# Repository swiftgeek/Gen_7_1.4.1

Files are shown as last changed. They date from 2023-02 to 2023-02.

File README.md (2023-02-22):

Known issues:

* PA6 missing trace to MCU and a short between PA6/PA7. Upstream `.pcb` file
doesn't match gerbers and PDFs/PNGs
* Board outline doesn't work well with OBV

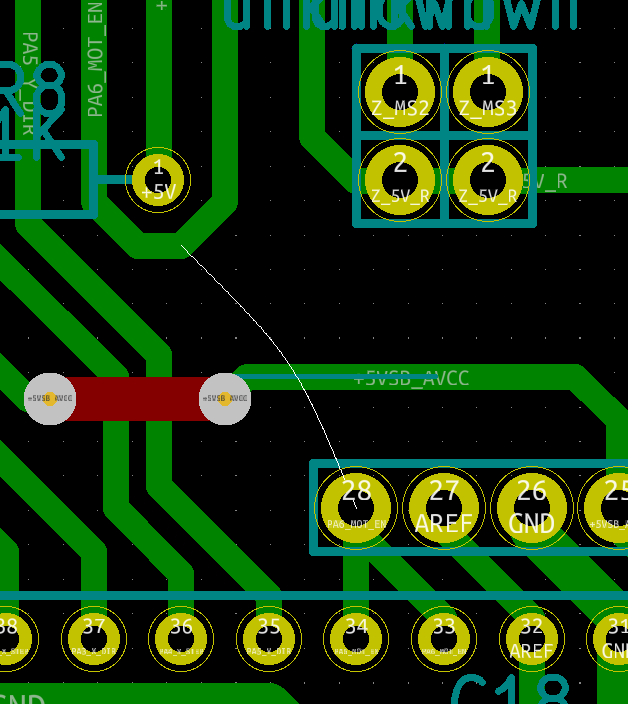
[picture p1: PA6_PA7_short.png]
Picture of short and missing trace Short and missng trace


TODO:

* Try importing gerber traces/layout into `pcb`/`pcbnew`, otherwise
set gerber render and background and try laying traces over it exactly.
* Generate PDFs and gerbers once fixed

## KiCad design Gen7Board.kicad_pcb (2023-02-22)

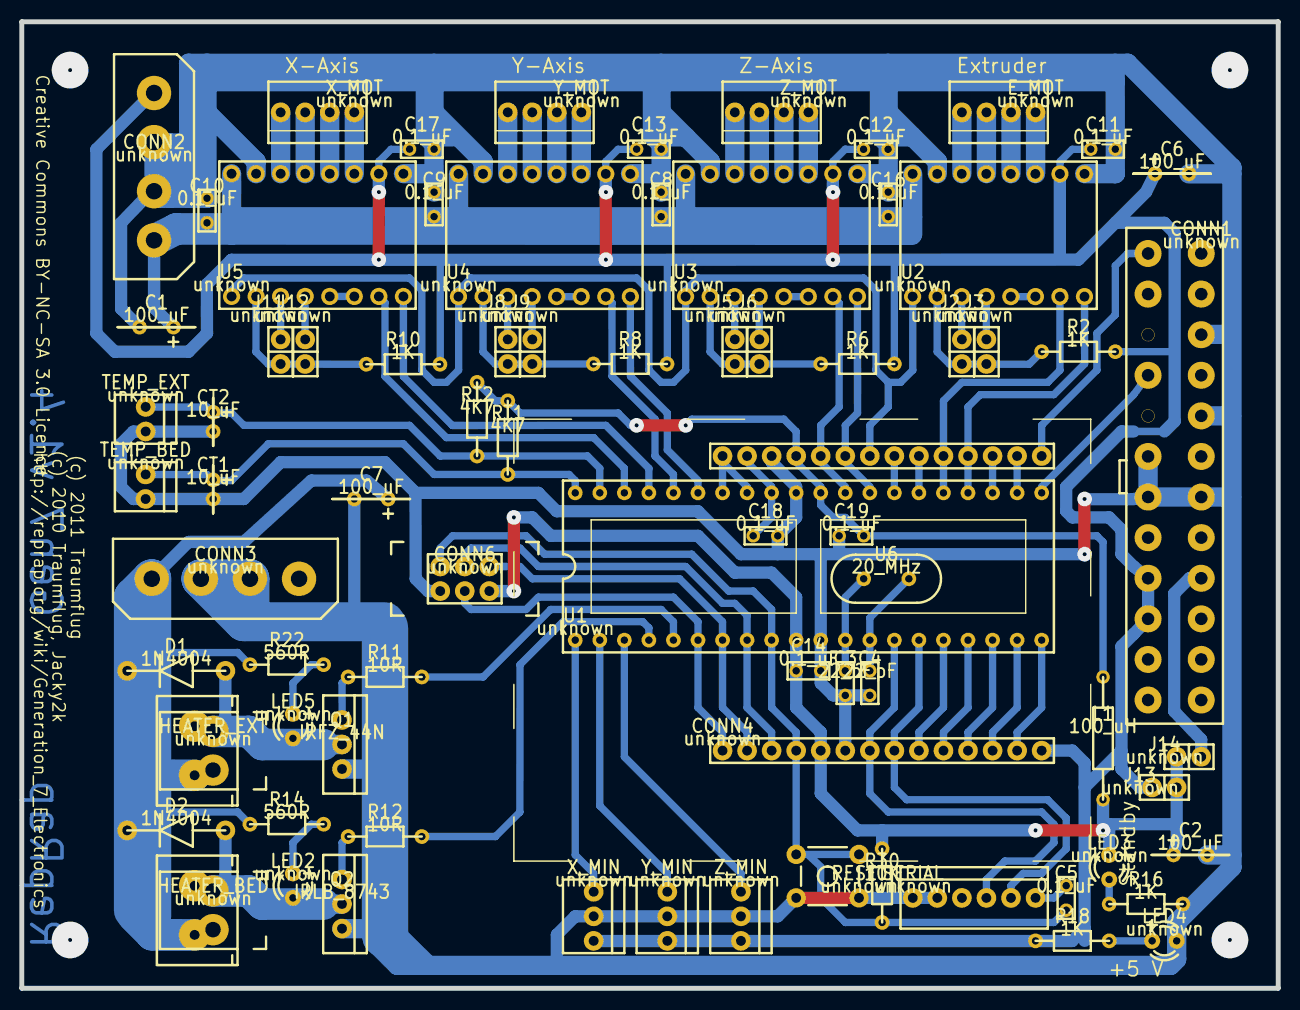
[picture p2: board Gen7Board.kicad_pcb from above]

Board: 2 copper layers, 130.0 x 100.0 mm, 76 parts (0 on the bottom side), 84 nets.

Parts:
C1: 100_uF; RCY3mm5_dup15
C2: 100_uF; RCY3mm5_dup26
C3: 22_pF; ACY100_dup1
C4: 22_pF; ACY100_dup13
C5: 0.1_uF; ACY100_dup7
C6: 100_uF; RCY3mm5
C7: 100_uF; RCY3mm5_dup42
C8: 0.1_uF; ACY100_dup36
C9: 0.1_uF; ACY100_dup37
C10: 0.1_uF; ACY100_dup38
C11: 0.1_uF; ACY100_dup39
C12: 0.1_uF; ACY100
C13: 0.1_uF; ACY100_dup0
C14: 0.1_uF; ACY100_dup2
C16: 0.1_uF; ACY100_dup14
C17: 0.1_uF; ACY100_dup33
C18: 0.1_uF; ACY100_dup34
C19: 0.1_uF; ACY100_dup35
CONN1: unknown; ATX20+4-1
CONN2: unknown; MOLEX_4_PIN
CONN3: unknown; MOLEX_4_PIN_dup40
CONN4: unknown; ExtensionBoard
CONN6: unknown; ICSP_HEADER
CT1: 10_uF; RCY2mm_dup50
CT2: 10_uF; RCY2mm
D1: 1N4004; 1N4004_dup48
D2: 1N4004
E_MOT: unknown; 100-4-1_dup51
HEATER_BED: unknown; Combi-2-1_dup44
HEATER_EXT: unknown; Combi-2-1
J2: unknown; JUMPER2_1_dup22
J3: unknown; JUMPER2_1_dup23
J5: unknown; JUMPER2_1_dup24
J6: unknown; JUMPER2_1_dup25
J8: unknown; JUMPER2_1_dup3
J9: unknown; JUMPER2_1_dup6
J11: unknown; JUMPER2_1_dup4
J12: unknown; JUMPER2_1_dup5
J13: unknown; JUMPER2_1
J14: unknown; JUMPER2_1_dup9
L1: 100_uH; ACY500_1
LED2: unknown; LED3_1_dup45
LED3: unknown; LED3_1_dup8
LED4: unknown; LED3_1_dup12
LED5: unknown; LED3_1
Q1: IRFZ_44N; TO-220-1
Q2: IRLB_8743; TO-220-1_dup41
R2: 1K; ACY300_1_dup27
R6: 1K; ACY300_1_dup28
R8: 1K; ACY300_1_dup29
R10: 1K; ACY300_1_dup30
R11: 10R; ACY300_1_dup46
R12: 10R; ACY300_1_dup43
R14: 560R; ACY300_1_dup47
R16: 1K; ACY300_1_dup11
R18: 1K; ACY300_1_dup31
R22: 560R; ACY300_1
R30: 10K; ACY300_1_dup20
RESET: unknown; MJTP1230-1
RT1: 4K7; ACY300_1_dup32
RT2: 4K7; ACY300_1_dup10
SERIAL: unknown; 100-6-1
TEMP_BED: unknown; 100-2-1
TEMP_EXT: unknown; 100-2-1_dup49
U1: unknown; DIP40_1
U2: unknown; POLOLUSTEPPER-1_dup17
U3: unknown; POLOLUSTEPPER-1_dup19
U4: unknown; POLOLUSTEPPER-1
U5: unknown; POLOLUSTEPPER-1_dup18
U6: 20_MHz; CRYSTAL_AS
X_MIN: unknown; 100-3-1
X_MOT: unknown; 100-4-1
Y_MIN: unknown; 100-3-1_dup16
Y_MOT: unknown; 100-4-1_dup52
Z_MIN: unknown; 100-3-1_dup21
Z_MOT: unknown; 100-4-1_dup53

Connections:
+3.3V_ATX: CONN1.11, CONN4.15
+5V: C6.1, C11.2, C12.2, C13.2, C17.2, CONN1.19, CONN1.20, CONN2.4, CONN4.14, J13.1, R2.1, R6.1, R8.1, R10.1, R18.1, U2.10, U3.10, U4.10, U5.10, X_MIN.3, Y_MIN.3, Z_MIN.3
+5VSB: C2.1, C14.2, CONN4.5, CONN6.2, J13.2, J14.1, L1.1, LED3.1, R30.2, U1.10
+5VSB_ATX: CONN1.9, J14.2
+5VSB_AVCC: C19.1, CONN4.25, L1.2, RT1.2, RT2.2, U1.30
AREF: C18.1, CONN4.27, U1.32
E_1A: E_MOT.2, U2.12
E_1B: E_MOT.1, U2.11
E_2A: E_MOT.3, U2.13
E_2B: E_MOT.4, U2.14
E_5V_R: J2.2, J3.2, R2.2, U2.2
E_MS2: J2.1, U2.3
E_MS3: J3.1, U2.4
E_SLP_RST: U2.5, U2.6
GND: C1.2, C2.2, C3.2, C4.2, C6.2, C7.2, C8.2, C9.2, C10.2, C11.1, C12.1, C13.1, C14.1, C16.2, C17.1, C18.2, C19.2, CONN1.3, CONN1.5, CONN1.7, CONN1.16, CONN1.17, CONN2.2, CONN2.3, CONN3.2, CONN3.3, CONN4.6, CONN4.26, CONN6.6, CT1.2, CT2.2, LED4.2, Q1.3, Q2.3, R16.2, RESET.1, SERIAL.1, SERIAL.2, TEMP_BED.2, TEMP_EXT.2, U1.11, U1.31, U2.9, U2.15, U3.9, U3.15, U4.9, U4.15, U5.9, U5.15, X_MIN.2, Y_MIN.2, Z_MIN.2
GND_HEATER_BED: D2.2, HEATER_BED.2, LED2.2, Q2.2
GND_HEATER_EXT: D1.2, HEATER_EXT.2, LED5.2, Q1.2
LED2_R: LED2.1, R14.2
LED3_R: LED3.2, R16.1
LED4_R: LED4.1, R18.2
LED5_R: LED5.1, R22.2
PA0_TEMP_BED: CT1.1, RT1.1, TEMP_BED.1, U1.40
PA1_TEMP_EXT: CT2.1, RT2.1, TEMP_EXT.1, U1.39
PA2_X_STEP: U1.38, U5.7
PA3_X_DIR: U1.37, U5.8
PA4_Y_STEP: U1.36, U4.7
PA5_Y_DIR: U1.35, U4.8
PA6_MOT_EN: CONN4.22, CONN4.28, U1.33, U1.34, U2.1, U3.1, U4.1, U5.1
PB0_X_MIN: U1.1, X_MIN.1
PB1_Y_MIN: U1.2, Y_MIN.1
PB2_Z_MIN: U1.3, Z_MIN.1
PB3_HEATER_BED: R12.2, U1.4
PB3_HEATER_BED_R: Q2.1, R12.1
PB3_HEATER_EXT_R: Q1.1, R11.1
PB4_HEATER_EXT: R11.2, U1.5
PB5_ICSP_MOSI: CONN4.1, CONN6.4, U1.6
PB6_ICSP_MISO: CONN4.2, CONN6.1, U1.7
PB7_ICSP_SCK: CONN4.3, CONN6.3, U1.8
PC0_SCL: CONN4.16, U1.22
PC1_SDA: CONN4.17, U1.23
PC2_E_STEP: CONN4.18, U1.24, U2.8
PC3_E_DIR: CONN4.19, U1.25, U2.7
PC4_TDO: CONN4.20, U1.26
PC5_TDI: CONN4.21, U1.27
PC6_Z_DIR: CONN4.23, U1.28, U3.8
PC7_Z_STEP: CONN4.24, U1.29, U3.7
PD0_RXD0: CONN4.7, SERIAL.4, U1.14
PD1_TXD0: CONN4.8, SERIAL.5, U1.15
PD2_RXD1_INT0: CONN4.9, U1.16
PD3_TXD1_INT1: CONN4.10, U1.17
PD4_XCK1_OC1B: CONN4.11, U1.18
PD5_OC1A: CONN4.12, U1.19
PD6_OC2B_ICP: CONN4.13, U1.20
PD7_ATX_PS_ON: CONN1.14, U1.21
RESET: C5.1, CONN4.4, CONN6.5, R30.1, RESET.2, U1.9
RESET_C: C5.2, SERIAL.6
Vheat: C7.1, CONN3.1, D1.1, D2.1, HEATER_BED.1, HEATER_EXT.1, R14.1, R22.1
Vmot: C1.1, C8.1, C9.1, C10.1, C16.1, CONN2.1, U2.16, U3.16, U4.16, U5.16
XTAL1: C4.1, U1.13, U6.1
XTAL2: C3.1, U1.12, U6.2
X_1A: U5.12, X_MOT.2
X_1B: U5.11, X_MOT.1
X_2A: U5.13, X_MOT.3
X_2B: U5.14, X_MOT.4
X_5V_R: J11.2, J12.2, R10.2, U5.2
X_MS2: J11.1, U5.3
X_MS3: J12.1, U5.4
X_SLP_RST: U5.5, U5.6
Y_1A: U4.12, Y_MOT.2
Y_1B: U4.11, Y_MOT.1
Y_2A: U4.13, Y_MOT.3
Y_2B: U4.14, Y_MOT.4
Y_5V_R: J8.2, J9.2, R8.2, U4.2
Y_MS2: J8.1, U4.3
Y_MS3: J9.1, U4.4
Y_SLP_RST: U4.5, U4.6
Z_1A: U3.12, Z_MOT.2
Z_1B: U3.11, Z_MOT.1
Z_2A: U3.13, Z_MOT.3
Z_2B: U3.14, Z_MOT.4
Z_5V_R: J5.2, J6.2, R6.2, U3.2
Z_MS2: J5.1, U3.3
Z_MS3: J6.1, U3.4
Z_SLP_RST: U3.5, U3.6

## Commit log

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2010-10-17 Gen7Board.pcb: fix the layer grouping to actually have a working solder and component side.
2010-10-17 Fixed a few things around the ATX20 connector:
    - The ATX20 symbol had "J?" as the default name which clashes with jumpers.
    - The ATX20 footprint had in addition to the above wrong pin numbers.
    - Fitted the new ATX20 connector footprint onto the board.
    - Removed the GND pad as this somehow doesn't work and there's more
    than enough space on the wide GND tracks.
    [Gen7Board.sch]
2010-10-17 Fix the Molex KK 100 3-pin connector footprint to comply with the data sheet.
2010-10-17 Gen7Board: replace 2-pin jumpers with solder jumpers.
    [Gen7Board.sch]
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2010-10-30 Gen7Board: modify the schematic to match the recent turn of the endstop connectors in the PCB.
    [Gen7Board.sch]
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2010-10-30 Made a new ICSP header symbol (for the pin labels) and fitted it into the schematics.
    [Gen7Board.sch]
2010-10-30 Following a contribution by Lanthan: Made a footprint for the ICSP header with matching pin numbering and wired the thing into the pcb.
    [Gen7Board.sch]
2010-12-09 Changed Opto Endstop connectors to match the layout of RAMPS.
    Yes, this is yet again and no, the endstops them selfs are not done yet.
    [Gen7Board.sch]
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2010-12-15 Board, by Jacky2k: Allow traces between between reset switch pins.
    Also add a data sheet for that switch and rename the footprint accordingly.
    [Gen7Board.sch]
2010-12-15 Board, by Jacky2k: move the reset switch's 5V to Vcc/5VSB.
    Reset was pulled "up" to 5V instead of 5VSB so the processor stayed
    in reset until the power supply turns on, a catch-22 condition.
    [Gen7Board.sch]
2010-12-15 Board, by Jacky2k: move temperature sensors from port PB to PA.
    This is neccessary, as only port PA features analog inputs.
    [Gen7Board.sch]
2010-12-15 Board: drop fuse R17.
    All known other boards don't have fuses either, so we also
    rely on the power supply's fuse.
    [Gen7Board.sch]
2010-12-15 Board: drop fuse R15 as well.
    Unfortunately, no simplification in the PCB layout this time.
    [Gen7Board.sch]
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2010-12-16 Board: remove one of the traces to the 5V pins of the ATX20 for simplification.
    [Gen7Board.sch]
2010-12-16 Board: replaced R11, R12 and R13 by 1KOhm.
    As recommended by the Gen2OnABoard Wiki page. Previous value was
    100KOhm.
    [Gen7Board.sch]
2010-12-16 Board: connected SLEEP and RESET directly.
    This is hinted in the breakout board data sheet on page 2 and
    page 4 of that document shows this pulls both pins high, due
    to an resistor already on that breakout board.
    [Gen7Board.sch]
2010-12-17 Board: removed R1, R5, R7 and R9 as they appear to be obsolete.
    The obsoleteness was found by comparing with other circuits like
    RAMPS, Repic.
    [Gen7Board.sch]
2010-12-17 Board: raised R2, R6, R8 and R10 to 100K from 2K7.
    100K should be sufficient to hold this input on High.
    [Gen7Board.sch]
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2010-12-18 Board: removed the jumper for MS1 of the Pololus.
    Now this signal is hardwired to High, making it unambiguous, despite
    of the lacking internal pulldown resistor.
    [Gen7Board.sch]
2010-12-18 Revert "Board: raised R2, R6, R8 and R10 to 100K from 2K7."
    This was a silly idea, as there are internal pulldown-resistors.
    Changed them now to 1K to have more resistors of the same value.
    [Gen7Board.sch]
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2010-12-18 Board: corrected D1, D2 and D3's footprint.
    This included using a reverted symbol in the schematics, as
    schematics and layout didn't agree in pin numbering. Yes,
    even with only 2 pins something like this can be wrong.
    [Gen7Board.sch]
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2010-12-18 Board: replaced the ATX12V connector with a Molex 4 pin one.
    More important here is to get the connector to the left side.
    [Gen7Board.sch]
2010-12-19 Board, by Jacky2k: add de-noise capacitor C14.
    [Gen7Board.sch]
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2010-12-19 Board: Jumper between 5V and 5VSB A Jumper was added to short 5V and 5VSB. The 5V pin of the molex connector was connected to the boards 5V, so it is possible to use the board without the 20 pin ATX 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
    [Gen7Board.sch]
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2010-12-19 Board: No more DRC errors, added I2C Header, Moved up the atmega for more space under it
    [Gen7Board.sch]
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2010-12-19 Board: Filter for AVCC A L/C Filter for AVCC was added and the 5V to 5VSB bridge jumper was moved
    [Gen7Board.sch]
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2010-12-19 Board: Moved wrong places GND line away from Q1
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2010-12-21 Board: replaced C5's footprint with an ACY100.
    This is the same as for all the other capacitors of that size.
    It required to turn R30 and L1 as well.
    [Gen7Board.sch]
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2010-12-21 Board: add a note about how to choose RT1 and RT2.
    This note was added to the schematic.
    [Gen7Board.sch]
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2011-01-08 Board: new serial header footprint.
    The new one is a Molex KK-100 6-pin to avoid plugging in the
    connector the wrong way. As everybody is free to change connectors
    to personal preference, the change in fact just gives a bit more
    space around the header.
    [Gen7Board.sch]
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2011-01-08 Board: connect all Pololu's Enable pins to ATmega's PA7.
    This allows to switch off the stepper motor also for power
    supplies not featuring an on/off pin.
    [Gen7Board.sch]
2011-01-08 Board: removed H1 and H2 from the schematics.
    These two headers were disconneted a long time ago anyways,
    just cluttering up the schematics.
    [Gen7Board.sch]
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2011-01-11 Board, by Jacky2k: add 5-pin header.
    This is to ease access to some of the unused ATmega pins.
    [Gen7Board.sch]
2011-01-11 Board: mark all non-GND tracks as "clearline".
    This doesn't change the appearance of the board, but makes laying
    a ground plane much easier.
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2011-01-15 Board: Change drill size and polygon clearance for FET's mounting holes.
    Drill size is now 3.3 mm, diameter of the clearance is 8 mm,
    both values fitting for M3 srews/nuts/washers. FET's housings
    are _not_ supposed to get electrical contact with GND, at least
    for some types of FETs.
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2011-01-24 Board: Added data sheet and footprint for the crystal.
    Also changed this footprint in the layout.
    [Gen7Board.sch]
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2011-01-24 Board, by Jacky2k: more copper around the jumper headers.
    This includes the 5-pin MISC header.
    Note there's a bug in the very popular 2009 version of PCB,
    which disallows the usage of dashs (-) in some footprint file names.
    [Gen7Board.sch]
2011-01-24 Board: switch remaining 100 nF value to 0.1 uF to match majority.
    No functional change.
    [Gen7Board.sch]
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2011-01-25 Board: Allow both, 0.200" and 4 mm spaced motor connectors.
    Funnily, the 4 mm ones are apparently better available in states with
    imperial measurement system, while the others are found easier in
    europe with it's metric system.
    Anyways, to get room for the double-footprint, the hole Pololu area
    had to go down 3 rasters (75 mil).
    [Gen7Board.sch]
2011-01-27 Board: add the connection to all EN pins in the schematic as well.
    Accidently, this was forgotten when drawing this into the board's
    layout, so the board remains unchanged.
    [Gen7Board.sch]
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2011-02-02 Board: move motor connectors up 25 mil to make room for the connector's snappers.
2011-02-02 Board: GND tracks shouldn't have polygon clearance.
2011-02-02 Board: reviewed all polarized capacitors.
    This included a new footprint for the 10uF ones. Footprint
    for the 100uF ones are unchanged, as 35V versions have the currently
    designed spacing. 25V ones are smaller, but the Pololus are spec'd
    for 35V, so some people may choose to use that current.
    [Gen7Board.sch]
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2011-02-26 Gen7Board: change a "4k7" to "4K7".
    Component values have to match case-sensitive to be recognized
    as being the same.
    [Gen7Board.sch]
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2011-03-07 Endstops: re-apply a small copper ring around mounting holes.
    This should avoid Visolate to pull an isolation path right through
    these mounting holes, risking a short by the mounting screw.
2011-03-07 Board: replace the TIP120 with an IRFZ 44N.
    The IRFZ 44N can switch 41 A instead of 5 A and costs only about
    20 cents more.
    [Gen7Board.sch]
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2011-03-07 Board: use the footprints also used in the Endstops.
    This also raises the resistor's drill sizes to 30 mil, getting
    the 28 mil drill closer to be obsolete.
    [Gen7Board.sch]
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2011-03-07 Board: replace the 5 mm LEDs with 3 mm ones.
    This also removes the requirement for the 43 mil drill, so we have
    now 9 drill sizes.
    [Gen7Board.sch]
2011-03-07 Board: use the same mounting holes as with the Endstops.
    This also gives them a small copper ring, avoiding shorts by the
    mounting screw when milling with Voronoi paths.
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2011-03-09 Board: have 3 jumpers for each of the possible 5V sources.
    These 3 sources are 5VSB from the ATX20, 5V from the Serial
    connector or 5V from the Molex 4-pin connector. You're supposed to
    fill exactly ONE of these jumpers at a time.
    [Gen7Board.sch]
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2011-03-09 Board: reduced the ICSP header drill size to 40 mil = 1.02 mm.
    Also fix the solder mask of this connector.
2011-03-09 Board: reduced drill size of the serial connector to 40 mil.
    Also fixed the solder mask of this connector.
2011-03-10 Board: Reduced the drill size if the Molex KK100 3-Pin to 40 mil.
    This finally removes the requirement for the 44 mil drill. The
    solder mask of these connectors was corrected also.
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2011-03-10 Board: make the coil have all round pins.
    This finally makes the board have round pins only, so the Gerber
    output is Visolate-compatible.
    [Gen7Board.sch]
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2011-03-10 Board: fix the MISC header's solder mask.
2011-03-10 Board: fix solder mask of 2-pin jumpers.
2011-03-10 Board: fix motor connector AKL_220-4 solder mask.
    As an exception, the solder mask relief was too big this time.
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2011-03-10 Board: fix the Molex 4-pin's solder mask.
2011-03-10 Board: connect HEATER1 and HEATER2 with PWM-able pins.
    Sometimes it's astonishing how long it takes to find such essential
    flaws.
    [Gen7Board.sch]
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2011-04-06 Added symbol and footprint for the TCST optical sensor.
    The footprint is for the TCST 11xx series, which doesn't have
    mounting holes.
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2011-05-23 Make use of this new combi footprint ...
    ... and allow the GND track near the top border to be wider, as
    there is more space now.
    [Gen7Board.sch]
2011-05-25 Removed the Molex .156 and the AKL 220 connector.
    They're no longer used and were replaced by the Combi-4 footprint.
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2011-05-25 Replace the heater connectors with that new Combi-2 type.
    Several enhancements:
    - Only two pins -> less confusion.
    - Thicker pins -> more current possible.
    - You can use screw terminals.
    [Gen7Board.sch]
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2011-05-26 Replace 3 pin thermistor headers with 2 pin ones.
    This not only lowers the price by a few cent, it also allows a
    simpler routing, removes a wire bridge and makes it unambiguous
    on where the thermistor should be connected.
    [Gen7Board.sch]
2011-06-03 Board: replaced the footprint for the ATX20 connector.
    The footprint has now 24 pins for compatibility with
    ATX24 power supplies.
    [Gen7Board.sch]
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2011-06-08 Board: made traces from the MOSFETs a bit shorter and thicker.
    There's a lot of current and this also makes a bit more room.
2011-06-08 Board: same clearance against copper planes for all tracks (32 mil).
    The endstop PCB was already fine.
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2011-06-11 Board: make the MOSFETs upright.
    This should allow better cooling and attaching a heatsink. Effectively,
    it just replaces the silk of the footprint ...
    Also made the GND trace there even thicker.
    [Gen7Board.sch]
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2011-06-29 Board: fix a misaligned mounting hole.
    The misalignment was probably introduced unintentionally.
2011-06-29 Board: fixed the designator of the Pololus on the silk screen.
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2023-02-22 Modify symbols to work with current gEDA
    ATMEGA644P-1 and ExtensionBoard were modified, otherwise errors like
    following one appear when trying to create netlist:
    Gen7Board.sch:CONN4-11: error: inconsistent values for "pinlabel": "PD4" vs. "XCK1" vs. "OC1B"
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2023-02-22 Final changes for public buggy 1.4.1 PCB
    [Gen7Board.kicad_pcb, Gen7Board.sch]

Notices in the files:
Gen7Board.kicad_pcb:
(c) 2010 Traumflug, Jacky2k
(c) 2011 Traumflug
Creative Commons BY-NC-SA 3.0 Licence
